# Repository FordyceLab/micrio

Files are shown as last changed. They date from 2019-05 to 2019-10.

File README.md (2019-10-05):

[Simple Project Download via OSF \[2 GB\]](https://osf.io/86wf5/?view_only=c3bfd653adfa457480bd9e34eeaa98bf) (click: Google Drive > Download as zip)

# micrIO:
An open-source <ins>micr</ins>ofluidic <ins>I</ins>nput-<ins>O</ins>utput platform comprising a specialized *autosampler* and *fraction collector*. 

This repository contains supplemental information for [`S.A. Longwell and P.M. Fordyce (under review)`](https://www.biorxiv.org/content/10.1101/655324v1). It details how to assemble micrIO, as well as the experiment/data analysis used to validate the platform. 

The Python software to control micrIO (and other devices such as *pressure manifolds*, *MFCS units*, and *syringe pumps*) is available as our pip-installable [`acqpack`](https://pypi.org/project/acqpack/) package (documentation [here](https://acqpack.readthedocs.io/en/latest/)).

Large files (videos, images) are included in the repository via git-lfs, which must be installed to have these files clone properly. Downloading the `.zip` from here will not include working versions of these files. (See [OSF: Google Drive](https://osf.io/86wf5/?view_only=c3bfd653adfa457480bd9e34eeaa98bf) mirror for easy viewing / downloading of these files).

[Full CAD Link](https://a360.co/2IcW9vt)

micrIO CAD (https://a360.co/2IcW9vt)

## [`assembly/`](https://github.com/FordyceLab/micrio/tree/master/assembly)
- [**`parts-list.gsheet`**](https://docs.google.com/spreadsheets/d/17_JYHVy769XvpJGD3QiEPhoSL2Djqnr2_NVfNIwoY9A/edit?usp=sharing) Start here. Details parts needed for each sub-assembly, example sourcing for commercial parts, and links to view/download custom parts (3D-printed/laser-cut).
- [**`parts/`**](https://github.com/FordyceLab/micrio/tree/master/assembly/parts) Contains `.stl` files for 3D-printed parts and `.pdf` files for laser-cut parts (formatted for a Universal Laser Systems cutter). For other file formats, see links within `parts-list.gsheet`. 
- [**`assembly.mp4`**](https://osf.io/6a3vq/?view_only=c3bfd653adfa457480bd9e34eeaa98bf) Walk-around of micrIO (to aid in assembly).

## [`validation/`](https://github.com/FordyceLab/micrio/tree/master/validation)
- [**`run/`**](https://github.com/FordyceLab/micrio/tree/master/validation/run)
    + [**`config/`**](https://github.com/FordyceLab/micrio/tree/master/validation/run/config) The `.yaml` config files, frame transformations, and platemaps.
    + [**`run.ipynb`**](https://github.com/FordyceLab/micrio/blob/master/validation/run/run.ipynb) The notebook used to script/record production of spectrally encoded beads.
    + [**`log/`**](https://github.com/FordyceLab/micrio/tree/master/validation/run/log) Log files produced from the run. 
    + [**`validation.mp4`**](https://osf.io/ydbtc/?view_only=c3bfd653adfa457480bd9e34eeaa98bf) Shows micrIO integrated into a setup to perform the validation experiment.
- [**`analysis/`**](https://github.com/FordyceLab/micrio/tree/master/validation/analysis)
    + **`images/`** Images of beads produced from the validation run. There are 10 channels, 4 of which were used in the manuscript's analysis (*brightfield*, *Dy: 572 nm*, *Eu: 620 nm*, *Sm: 650*).
    + [**`bead_analysis.ipynb`**](https://github.com/FordyceLab/micrio/blob/master/validation/analysis/bead_analysis.ipynb) Image analysis pipeline used to identify beads and generate size and channel intensity figures and statistics.

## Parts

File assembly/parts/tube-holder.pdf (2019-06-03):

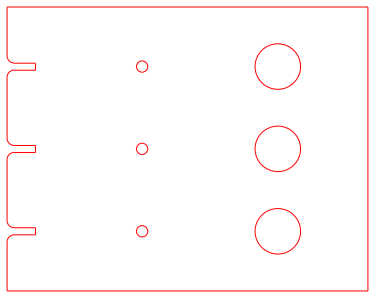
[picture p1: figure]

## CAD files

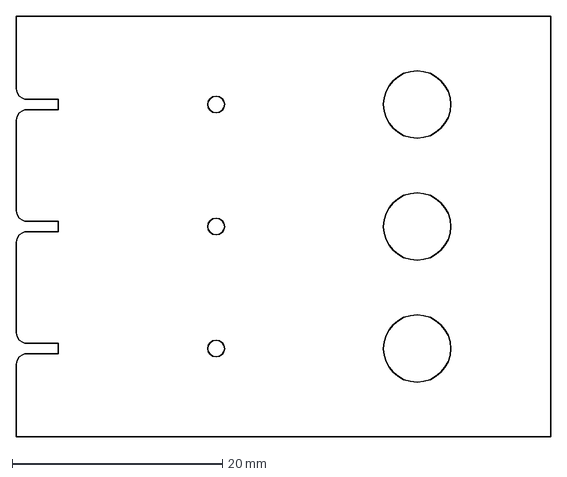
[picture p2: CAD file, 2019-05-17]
assembly/parts/tube-holder.dxf
50.8 x 40.0 mm

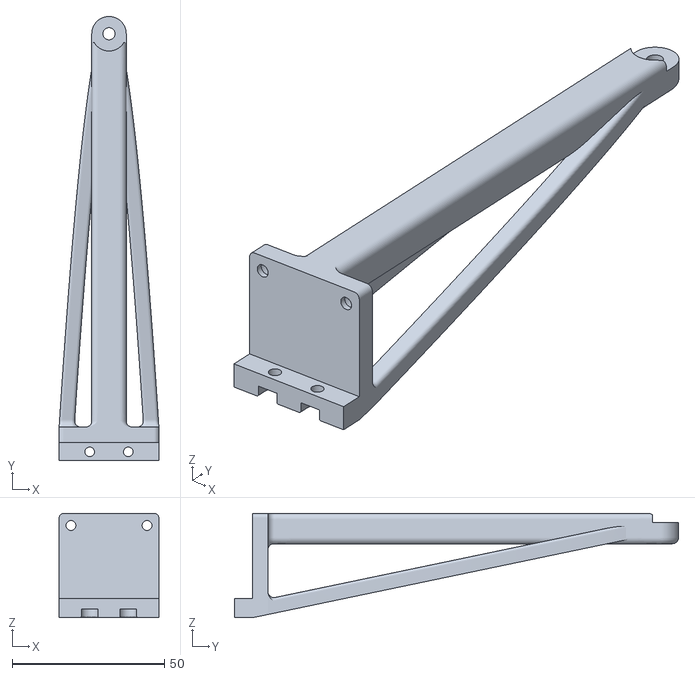
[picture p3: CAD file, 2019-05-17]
assembly/parts/sampler-arm.stl
32.8 x 146.0 x 34.3

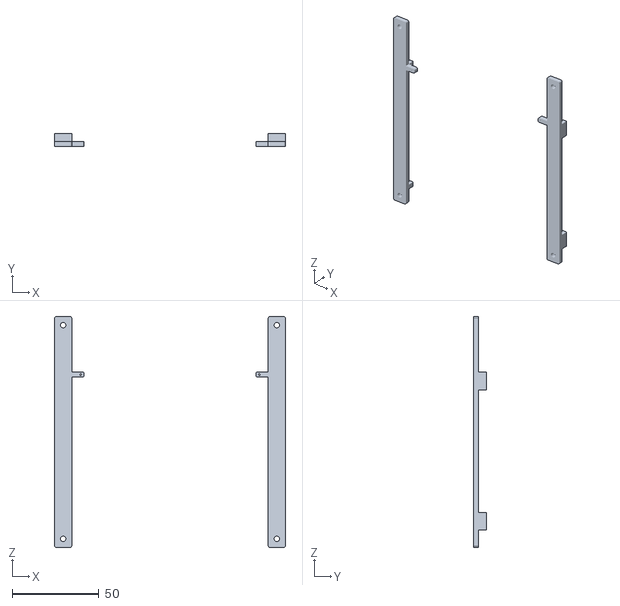
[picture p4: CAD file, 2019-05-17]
assembly/parts/plate-holder_LR.stl
133.5 x 7.50 x 133.5

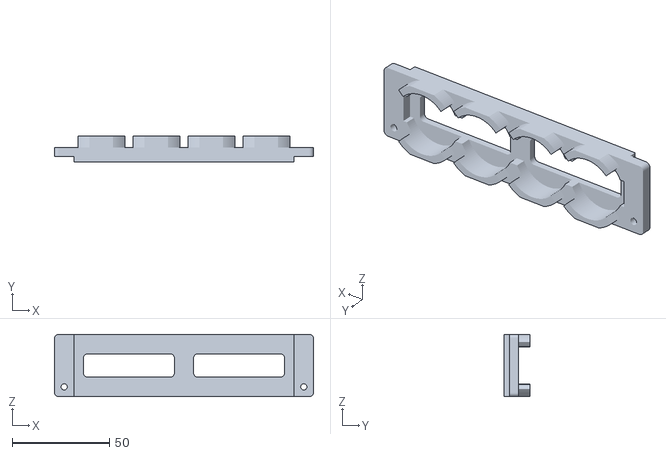
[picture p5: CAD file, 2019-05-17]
assembly/parts/4-vial-holder.stl
133.5 x 13.5 x 32.0

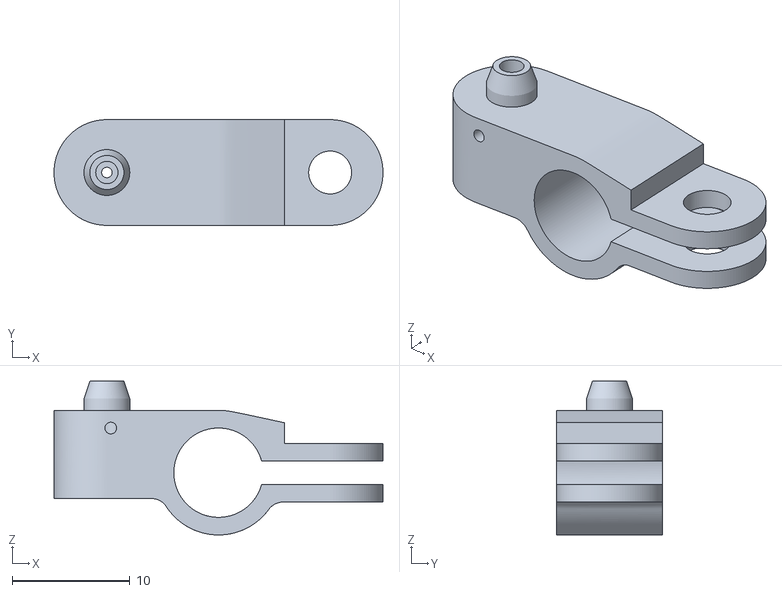
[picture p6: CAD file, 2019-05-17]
assembly/parts/sheath-nozzle.stl
28.0 x 9.00 x 13.1

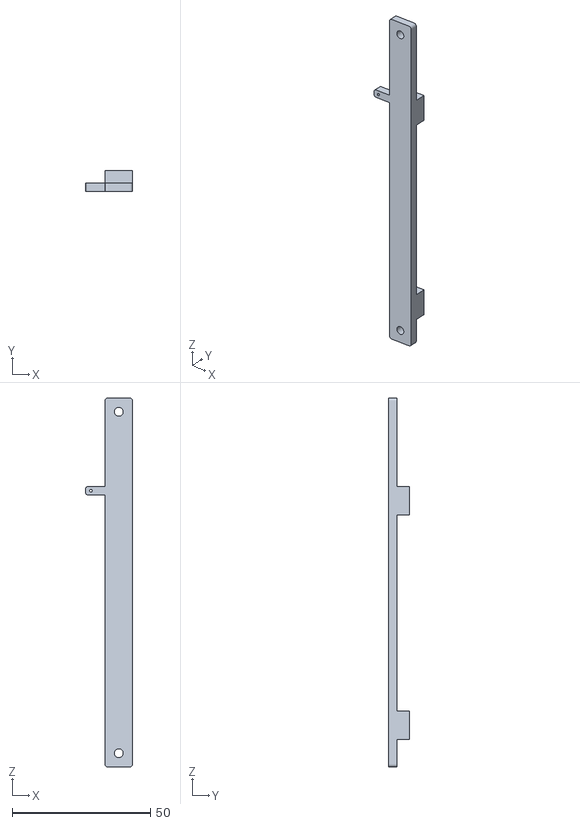
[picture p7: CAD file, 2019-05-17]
assembly/parts/plate-holder_L.stl
17.1 x 7.50 x 133.5

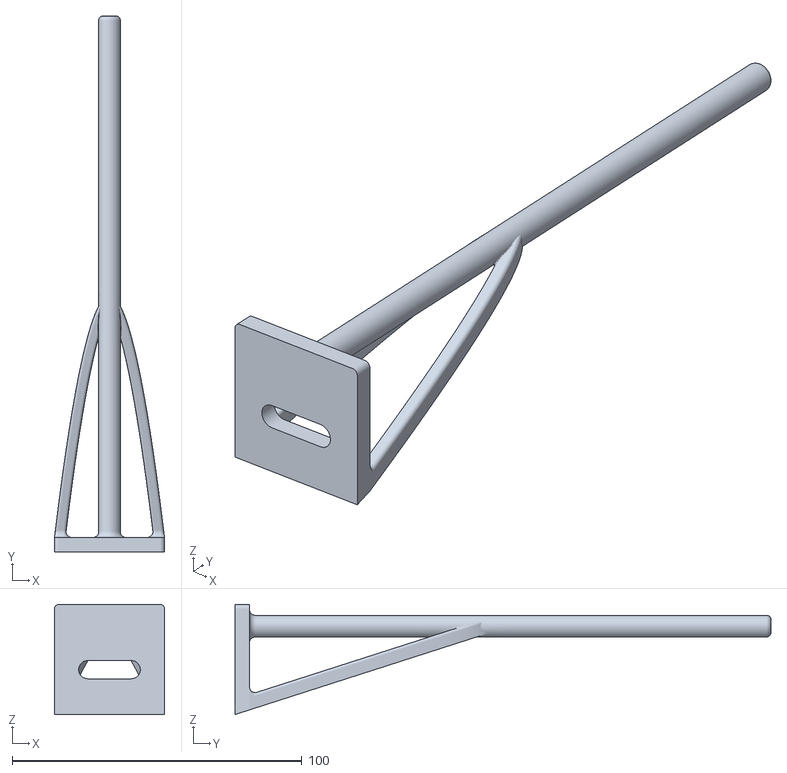
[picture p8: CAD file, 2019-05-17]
assembly/parts/collector-arm.stl
38.0 x 185.0 x 38.0

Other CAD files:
assembly/parts/plate-holder_R.stl

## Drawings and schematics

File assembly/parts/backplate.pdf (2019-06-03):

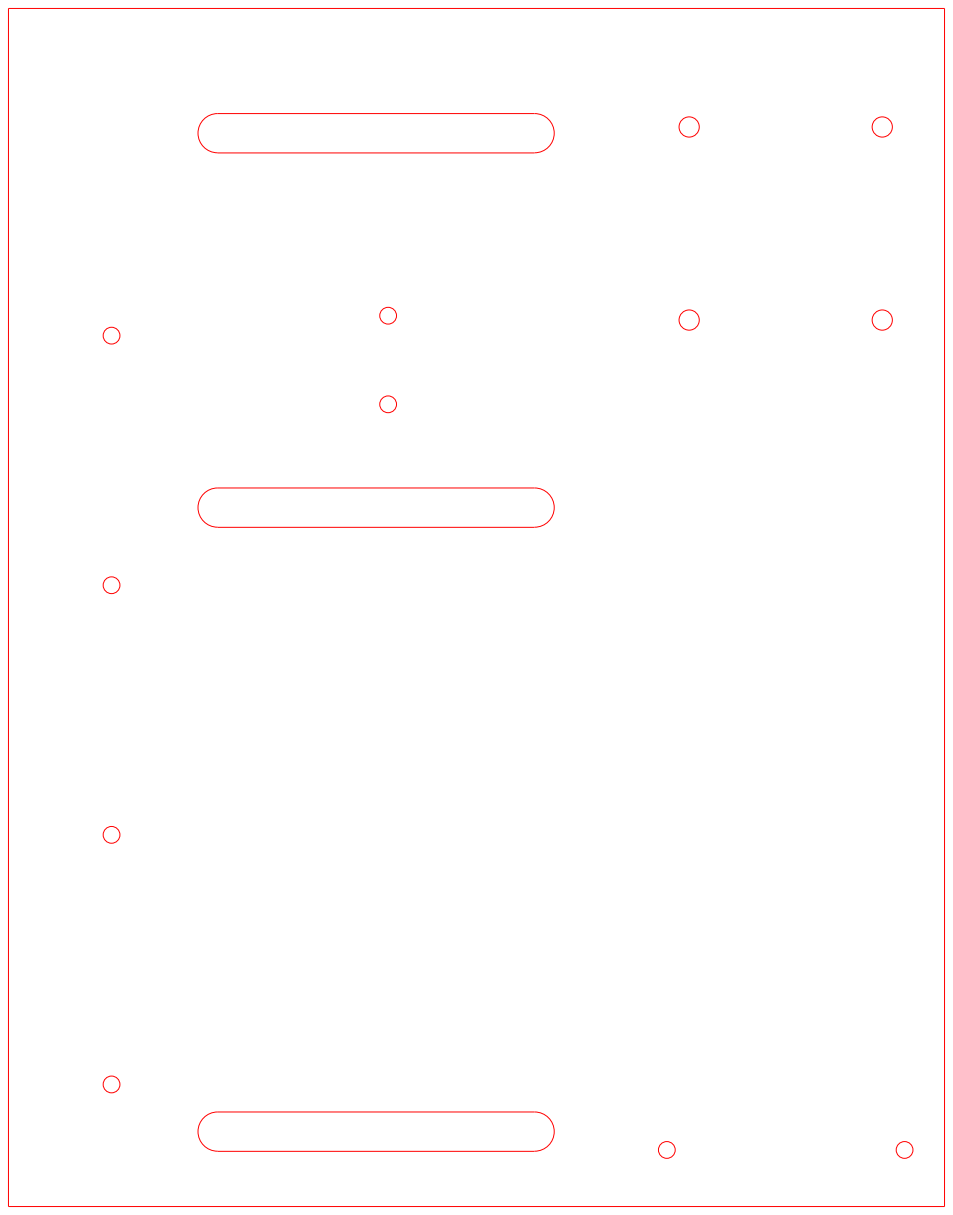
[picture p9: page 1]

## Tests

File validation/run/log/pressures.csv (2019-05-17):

 | wash | sampler | oil
prime | 1.0 | 13.0 | 1.98674590684
beads | 1.0 | 0.476086558139 | 1.98674590684
flush | 13.0 | 1.0 | 15.0

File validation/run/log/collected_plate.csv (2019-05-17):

n | s | r | c | well | contents | vial | x | y | z
0 | 0 | 0 | 0 | A01 | eu | 1.0 | 0 | 0.0 | 0
1 | 1 | 0 | 1 | A02 |  |  | 17 | 0.0 | 0
2 | 2 | 0 | 2 | A03 | dy | 2.0 | 34 | 0.0 | 0
3 | 3 | 0 | 3 | A04 |  |  | 51 | 0.0 | 0
4 | 4 | 0 | 4 | A05 | sm | 3.0 | 68 | 0.0 | 0
5 | 5 | 0 | 5 | A06 |  |  | 85 | 0.0 | 0
6 | 11 | 1 | 0 | B01 |  |  | 0 | 12.143 | 0
7 | 10 | 1 | 1 | B02 |  |  | 17 | 12.143 | 0
8 | 9 | 1 | 2 | B03 |  |  | 34 | 12.143 | 0
9 | 8 | 1 | 3 | B04 |  |  | 51 | 12.143 | 0
10 | 7 | 1 | 4 | B05 |  |  | 68 | 12.143 | 0
11 | 6 | 1 | 5 | B06 |  |  | 85 | 12.143 | 0
12 | 12 | 2 | 0 | C01 | waste1 |  | 0 | 24.286 | 0
13 | 13 | 2 | 1 | C02 | sm | 6.0 | 17 | 24.286 | 0
14 | 14 | 2 | 2 | C03 |  |  | 34 | 24.286 | 0
15 | 15 | 2 | 3 | C04 | dy | 5.0 | 51 | 24.286 | 0
16 | 16 | 2 | 4 | C05 |  |  | 68 | 24.286 | 0
17 | 17 | 2 | 5 | C06 | eu | 4.0 | 85 | 24.286 | 0
18 | 23 | 3 | 0 | D01 |  |  | 0 | 36.429 | 0
19 | 22 | 3 | 1 | D02 |  |  | 17 | 36.429 | 0
20 | 21 | 3 | 2 | D03 |  |  | 34 | 36.429 | 0
21 | 20 | 3 | 3 | D04 |  |  | 51 | 36.429 | 0
22 | 19 | 3 | 4 | D05 |  |  | 68 | 36.429 | 0
23 | 18 | 3 | 5 | D06 |  |  | 85 | 36.429 | 0
24 | 24 | 4 | 0 | E01 | eu | 7.0 | 0 | 48.572 | 0
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

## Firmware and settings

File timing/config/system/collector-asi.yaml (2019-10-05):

# Set the following to match your device's connection settings
# See this link for more details:
# http://pyserial.readthedocs.io/en/latest/pyserial_api.html
serial: 
  port: COM5                 # () com port
  baudrate: 115200           # (115200) baud rate
  bytesize: 8                # (8) number of data bits
  parity: N                  # (N) enable parity checking
  stopbits: 1                # (1) number of stopbits
  timeout:                   # () read timeout value
  xonxoff: False             # (False) enable software flow control
  rtscts: False              # (False) enable hardware (RTS/CTS) flow control
  writeTimeout:              # () write timeout value
  dsrdtr: False              # (False) enable hardware (DSR/DTR) flow control
  interCharTimeout:          # () 

prefix: ""
terminator: "\r"             # character to tell controller to run buffer contents

conv: 10000                  # (10000) number of stage units per mm (eg 10000 ASI units = 1 mm)

init_dir:
  x_dir: -1                  # (1) direction to seek hall-effect limit when initializing (-1 min, +1 max)
  y_dir: 1                   # (1) direction to seek hall-effect limit when initializing (-1 min, +1 max)
